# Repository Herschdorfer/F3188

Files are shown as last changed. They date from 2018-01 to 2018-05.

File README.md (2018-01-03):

# F3188

## Notes

| CSR PIN | F3188 PIN | Notes |
| --- | --- |---|
| RST# | RST |Reset pin needs min 2.4s low to shutdown the Chip. has a build in Pull-Up Resistor|
| VREGENABLE | POWER_EN |A high signal powers up the chip.|
|  |  |Its tolerant to the VBAT. Button should be connected to VBAT.|
|  |  |Can, after power up, be used for other things. Has a build in Pull-Down.|
| ? | VCC | Not sure if connected directly to a pin on the CSR8645 |
| VBAT | VBAT | seems to be direclty connected to VBAT |
| SPI_PCM# | SPI_PCM | High for SPI operation|
| | | LOW for PCM operation|

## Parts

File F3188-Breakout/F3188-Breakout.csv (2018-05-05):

Source: | E:/owncloud/projekte/F3188/F3188-Breakout/F3188-Breakout.sch
Date: | 05.02.2018 18:05:13
Tool: | Eeschema 4.0.7
Component Count: | 19
Ref | Value | Footprint | Datasheet | Manufacturer | Vendor
D1 | LED GREEN | LEDs:LED_0805_HandSoldering
D2 | LED BLUE | LEDs:LED_0805_HandSoldering
D3 | LED RED | LEDs:LED_0805_HandSoldering
J1 | Conn_01x03 | Pin_Headers:Pin_Header_Straight_1x03_Pitch2.54mm
J2 | Conn_01x14 | Pin_Headers:Pin_Header_Straight_1x14_Pitch2.54mm
J3 | Conn_01x09 | Pin_Headers:Pin_Header_Straight_1x09_Pitch2.54mm
J5 | Conn_01x17 | Pin_Headers:Pin_Header_Straight_1x17_Pitch2.54mm
J6 | Conn_01x01 | Pin_Headers:Pin_Header_Straight_1x01_Pitch2.54mm
R1 | 1k | Resistors_SMD:R_0805_HandSoldering
R2 | 1k | Resistors_SMD:R_0805_HandSoldering
R3 | 1k | Resistors_SMD:R_0805_HandSoldering
SW1 | VOL+ | Buttons_Switches_THT:SW_TH_Tactile_Omron_B3F-10xx
SW2 | VOL- | Buttons_Switches_THT:SW_TH_Tactile_Omron_B3F-10xx
SW3 | TRACK+ | Buttons_Switches_THT:SW_TH_Tactile_Omron_B3F-10xx
SW4 | TRACK- | Buttons_Switches_THT:SW_TH_Tactile_Omron_B3F-10xx
SW5 | PLAY | Buttons_Switches_THT:SW_TH_Tactile_Omron_B3F-10xx
SW6 | PWR | Buttons_Switches_THT:SW_TH_Tactile_Omron_B3F-10xx
SW7 | RST | Buttons_Switches_THT:SW_TH_Tactile_Omron_B3F-10xx
U1 | F-3188_CSR8645 | modules:F-3188_CSR8645

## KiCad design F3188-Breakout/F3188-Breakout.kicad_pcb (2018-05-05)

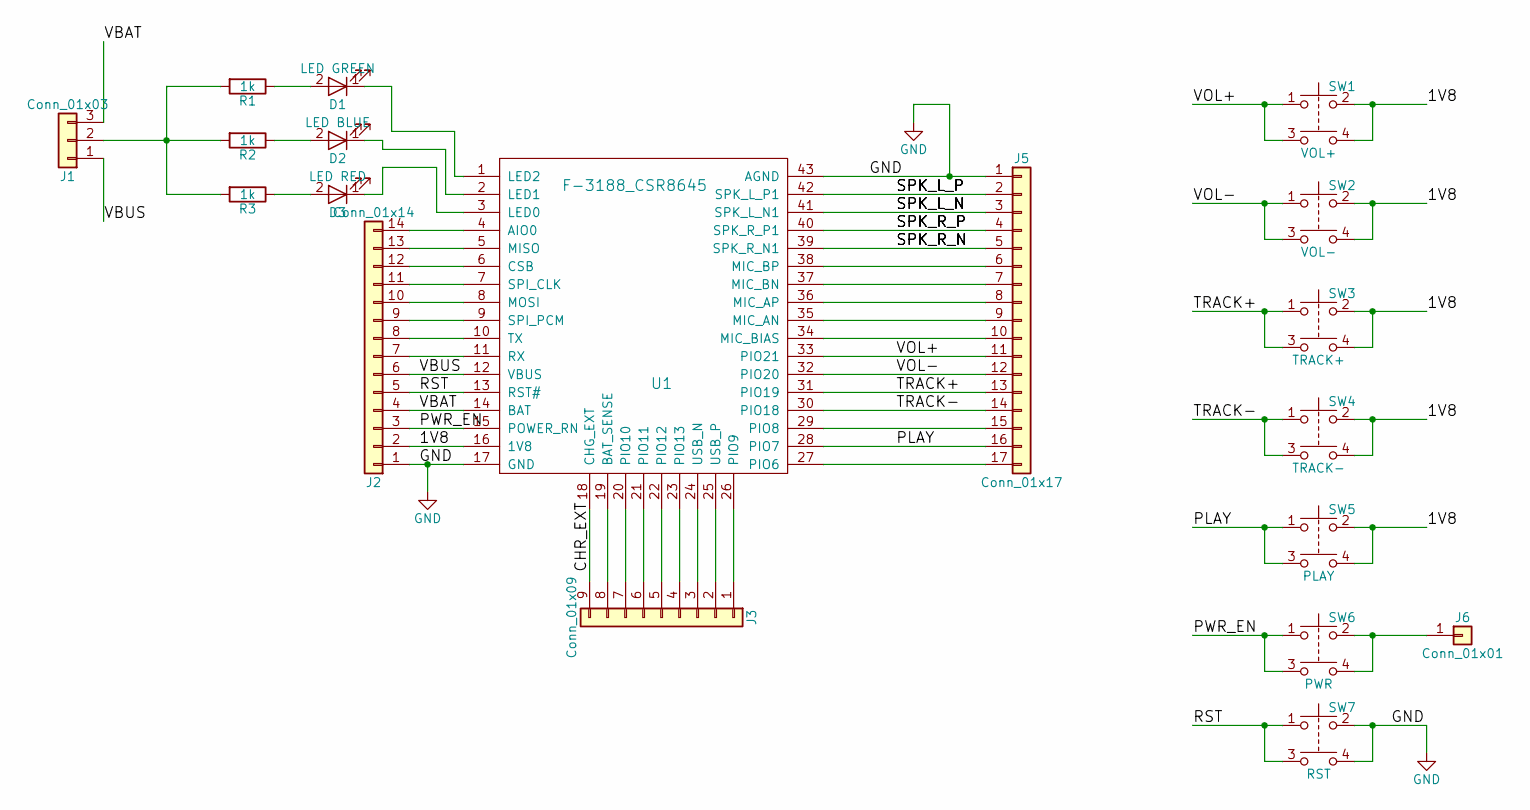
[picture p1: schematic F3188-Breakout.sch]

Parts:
D1: LED GREEN; LED_0805_HandSoldering
D2: LED BLUE; LED_0805_HandSoldering
D3: LED RED; LED_0805_HandSoldering
J1: Conn_01x03; Pin_Header_Straight_1x03_Pitch2.54mm
J2: Conn_01x14; Pin_Header_Straight_1x14_Pitch2.54mm
J3: Conn_01x09; Pin_Header_Straight_1x09_Pitch2.54mm
J5: Conn_01x17; Pin_Header_Straight_1x17_Pitch2.54mm
J6: Conn_01x01; Pin_Header_Straight_1x01_Pitch2.54mm
R1, R2, R3: 1k; R_0805_HandSoldering
SW1: VOL+; SW_TH_Tactile_Omron_B3F-10xx
SW2: VOL-; SW_TH_Tactile_Omron_B3F-10xx
SW3: TRACK+; SW_TH_Tactile_Omron_B3F-10xx
SW4: TRACK-; SW_TH_Tactile_Omron_B3F-10xx
SW5: PLAY; SW_TH_Tactile_Omron_B3F-10xx
SW6: PWR; SW_TH_Tactile_Omron_B3F-10xx
SW7: RST; SW_TH_Tactile_Omron_B3F-10xx
U1: F-3188_CSR8645

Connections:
/1V8: J2.2, SW1.2, SW1.4, SW2.2, SW2.4, SW3.2, SW3.4, SW4.2, SW4.4, SW5.2, SW5.4, U1.16 (1V8)
/CHR_EXT: J3.9, U1.18 (CHG_EXT)
/PLAY: J5.16, SW5.1, SW5.3, U1.28 (PIO7)
/PWR_EN: J2.3, SW6.1, SW6.3, U1.15 (POWER_RN)
/RST: J2.5, SW7.1, SW7.3, U1.13 (RST#)
/SPK_L_N: J5.3, U1.41 (SPK_L_N1)
/SPK_L_P: J5.2, U1.42 (SPK_L_P1)
/SPK_R_N: J5.5, U1.39 (SPK_R_N1)
/SPK_R_P: J5.4, U1.40 (SPK_R_P1)
/TRACK+: J5.13, SW3.1, SW3.3, U1.31 (PIO19)
/TRACK-: J5.14, SW4.1, SW4.3, U1.30 (PIO18)
/VBAT: J1.3, J2.4, U1.14 (BAT)
/VBUS: J1.1, J2.6, U1.12 (VBUS)
/VOL+: J5.11, SW1.1, SW1.3, U1.33 (PIO21)
/VOL-: J5.12, SW2.1, SW2.3, U1.32 (PIO20)
GND: J2.1, J5.1, SW7.2, SW7.4, U1.17 (GND), U1.43 (AGND)
unnamed: D1.1 (K), U1.1 (LED2)
unnamed: D1.2 (A), R1.1
unnamed: D2.1 (K), U1.2 (LED1)
unnamed: D2.2 (A), R2.1
unnamed: D3.1 (K), U1.3 (LED0)
unnamed: D3.2 (A), R3.1
unnamed: J1.2, R1.2, R2.2, R3.2
unnamed: J2.7, U1.11 (RX)
unnamed: J2.8, U1.10 (TX)
unnamed: J2.9, U1.9 (SPI_PCM)
unnamed: J2.10, U1.8 (MOSI)
unnamed: J2.11, U1.7 (SPI_CLK)
unnamed: J2.12, U1.6 (CSB)
unnamed: J2.13, U1.5 (MISO)
unnamed: J2.14, U1.4 (AIO0)
unnamed: J3.1, U1.26 (PIO9)
unnamed: J3.2, U1.25 (USB_P)
unnamed: J3.3, U1.24 (USB_N)
unnamed: J3.4, U1.23 (PIO13)
unnamed: J3.5, U1.22 (PIO12)
unnamed: J3.6, U1.21 (PIO11)
unnamed: J3.7, U1.20 (PIO10)
unnamed: J3.8, U1.19 (BAT_SENSE)
unnamed: J5.6, U1.38 (MIC_BP)
unnamed: J5.7, U1.37 (MIC_BN)
unnamed: J5.8, U1.36 (MIC_AP)
unnamed: J5.9, U1.35 (MIC_AN)
unnamed: J5.10, U1.34 (MIC_BIAS)
unnamed: J5.15, U1.29 (PIO8)
unnamed: J5.17, U1.27 (PIO6)
unnamed: J6.1, SW6.2, SW6.4

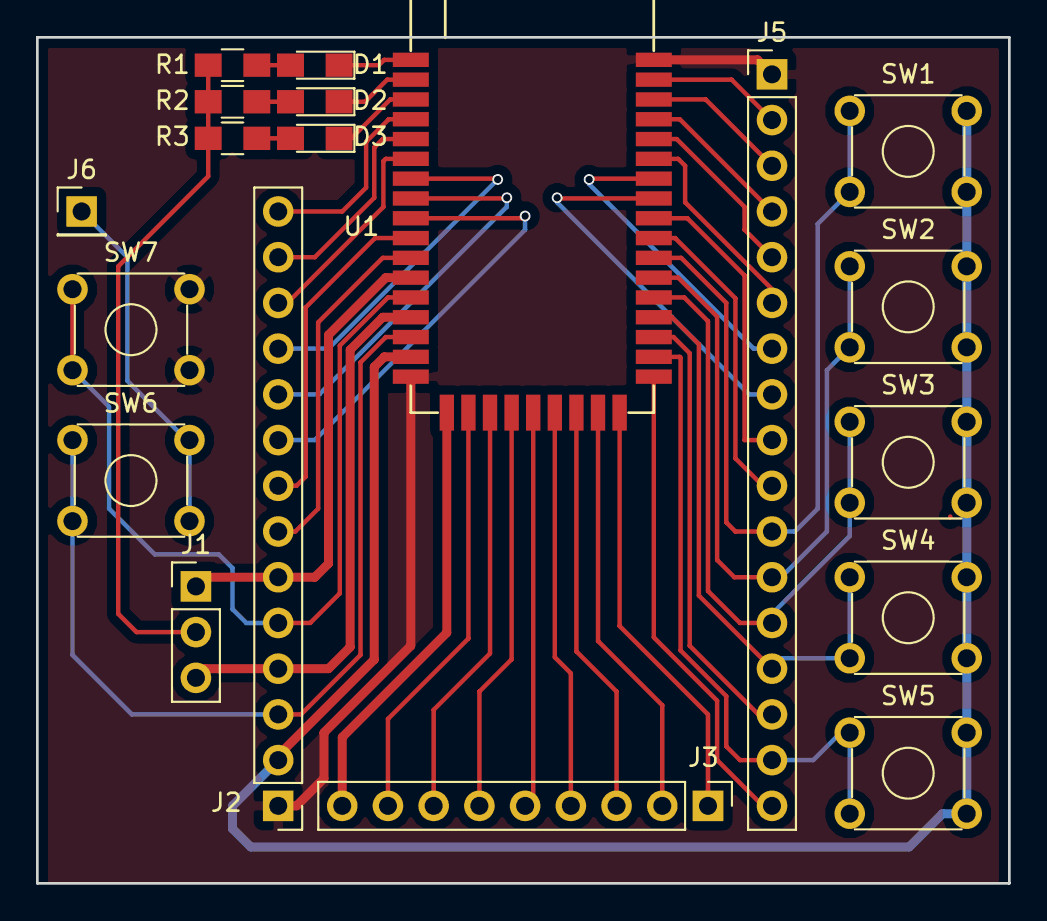
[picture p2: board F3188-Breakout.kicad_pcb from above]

Board: 2 copper layers, 54.0 x 47.0 mm, 19 parts (0 on the bottom side), 47 nets.
